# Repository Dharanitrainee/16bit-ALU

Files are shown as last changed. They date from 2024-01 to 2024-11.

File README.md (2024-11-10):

<h1>16-bit ALU with ESP32 Control Unit</h1>

<p>This project implements a 16-bit Arithmetic Logic Unit (ALU) using TTL (74 series) digital integrated circuits. The control unit is built using an ESP32 microcontroller, enhancing functionality with a user-friendly interface via an OLED display and a rotary encoder for selecting operations.</p>

<blockquote>
  <strong>Disclaimer</strong>: This is my first PCB design, and there may be flaws.This may be the worls worst ALU!. Any feedback or suggestions for improvement are welcome.
</blockquote>

<h2>Features</h2>

<ul>
  <li><strong>Arithmetic Operations</strong>: Addition, Subtraction, Increment, Decrement.</li>
  <li><strong>Logical Operations</strong>: AND, OR, XOR, NOT.</li>
  <li><strong>User Interface</strong>: An OLED display shows the current operation, and a rotary encoder allows for easy selection of operations.</li>
  <li><strong>Control Mechanism</strong>: ESP32 provides control signals and manages data flow within the ALU using shift registers.</li>
</ul>

<h2>Components Used</h2>

<ul>
  <li><strong>TTL ICs (74 series)</strong> for logic implementation</li>
  <li><strong>ESP32 microcontroller</strong> for control signals</li>
  <li><strong>OLED Display (SH1106)</strong> for displaying selected operation and result</li>
  <li><strong>Rotary Encoder (KY-040)</strong> for operation selection</li>
  <li><strong>Shift Registers (74HC595)</strong> for handling input/output</li>
</ul>

<h2>Project Structure</h2>

<ul>
  <li><code>main_code.ino</code>: The primary Arduino code for the ESP32, managing the control signals, encoder input, OLED output, and ALU operations.</li>
  <li><code>images/</code>: Contains bitmaps for icons representing each operation.</li>
  <li><code>README.md</code>: Project documentation.</li>
</ul>

<h2>How It Works</h2>

<ol>
  <li><strong>Control Unit</strong>: The ESP32 microcontroller generates control signals based on user input from the rotary encoder. The OLED screen displays the current operation, input values, and results.</li>
  <li><strong>ALU Operations</strong>: The ALU performs selected operations on 16-bit data, interfaced via shift registers.</li>
  <li><strong>Result Display</strong>: The result of the operation is shown on the OLED display.</li>
</ol>

<h2>Setup and Usage</h2>

<ol>
  <li>Connect the ESP32 to the OLED display and rotary encoder.</li>
  <li>Interface the shift registers with TTL ICs to implement the 16-bit ALU logic.</li>
  <li>Load the Arduino code onto the ESP32.</li>
  <li>Use the rotary encoder to select the desired operation and input values, then view the result on the OLED display.</li>
</ol>

<h2>Future Improvements</h2>

<ul>
  <li>Expand operations to include multiplication and division.</li>
  <li>Optimize the control signal generation for improved speed and accuracy.</li>
  <li>Add support for additional user inputs or controls to expand functionality.</li>
</ul>

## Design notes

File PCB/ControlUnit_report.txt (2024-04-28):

PCB statistics report
=====================
- Date: Sat 03 Feb 2024 10:58:33 PM IST
- Project: ControlUnit
- Board name: ControlUnit

Board
-----
- Width: 119.0000 mm
- Height: 119.3029 mm
- Area: 14175.4904 mm²

Pads
----
- Through hole: 217
- SMD: 88
- Connector: 0
- NPTH: 0

Vias
----
- Through vias: 27
- Blind/buried: 0
- Micro vias: 0

Components
----------

| | Front Side | Back Side | Total |
|---|---|---|---|
|THT: | 16 | 0 | 16 |
|SMD: | 31 | 0 | 31 |
|Unspecified:  | 4 | 0 | 4 |
|Total: | 51 | 0 | 51 |

Drill holes
-----------

| Count | Shape | X Size | Y Size | Plated | Via/Pad | Start Layer | Stop Layer |
|---|---|---|---|---|---|---|---|
| 80 | Round | 0.8000 mm | 0.8000 mm | PTH | Pad | F.Cu | B.Cu |
| 79 | Round | 0.5000 mm | 0.5000 mm | PTH | Pad | F.Cu | B.Cu |
| 38 | Round | 1.0200 mm | 1.0200 mm | PTH | Pad | F.Cu | B.Cu |
| 27 | Round | 0.3000 mm | 0.3000 mm | PTH | Via | F.Cu | B.Cu |
| 10 | Round | 1.0160 mm | 1.0160 mm | PTH | Pad | F.Cu | B.Cu |
| 4 | Round | 3.2000 mm | 3.2000 mm | PTH | Pad | F.Cu | B.Cu |
| 4 | Round | 1.0000 mm | 1.0000 mm | PTH | Pad | F.Cu | B.Cu |
| 2 | Round | 1.3000 mm | 1.3000 mm | PTH | Pad | F.Cu | B.Cu |

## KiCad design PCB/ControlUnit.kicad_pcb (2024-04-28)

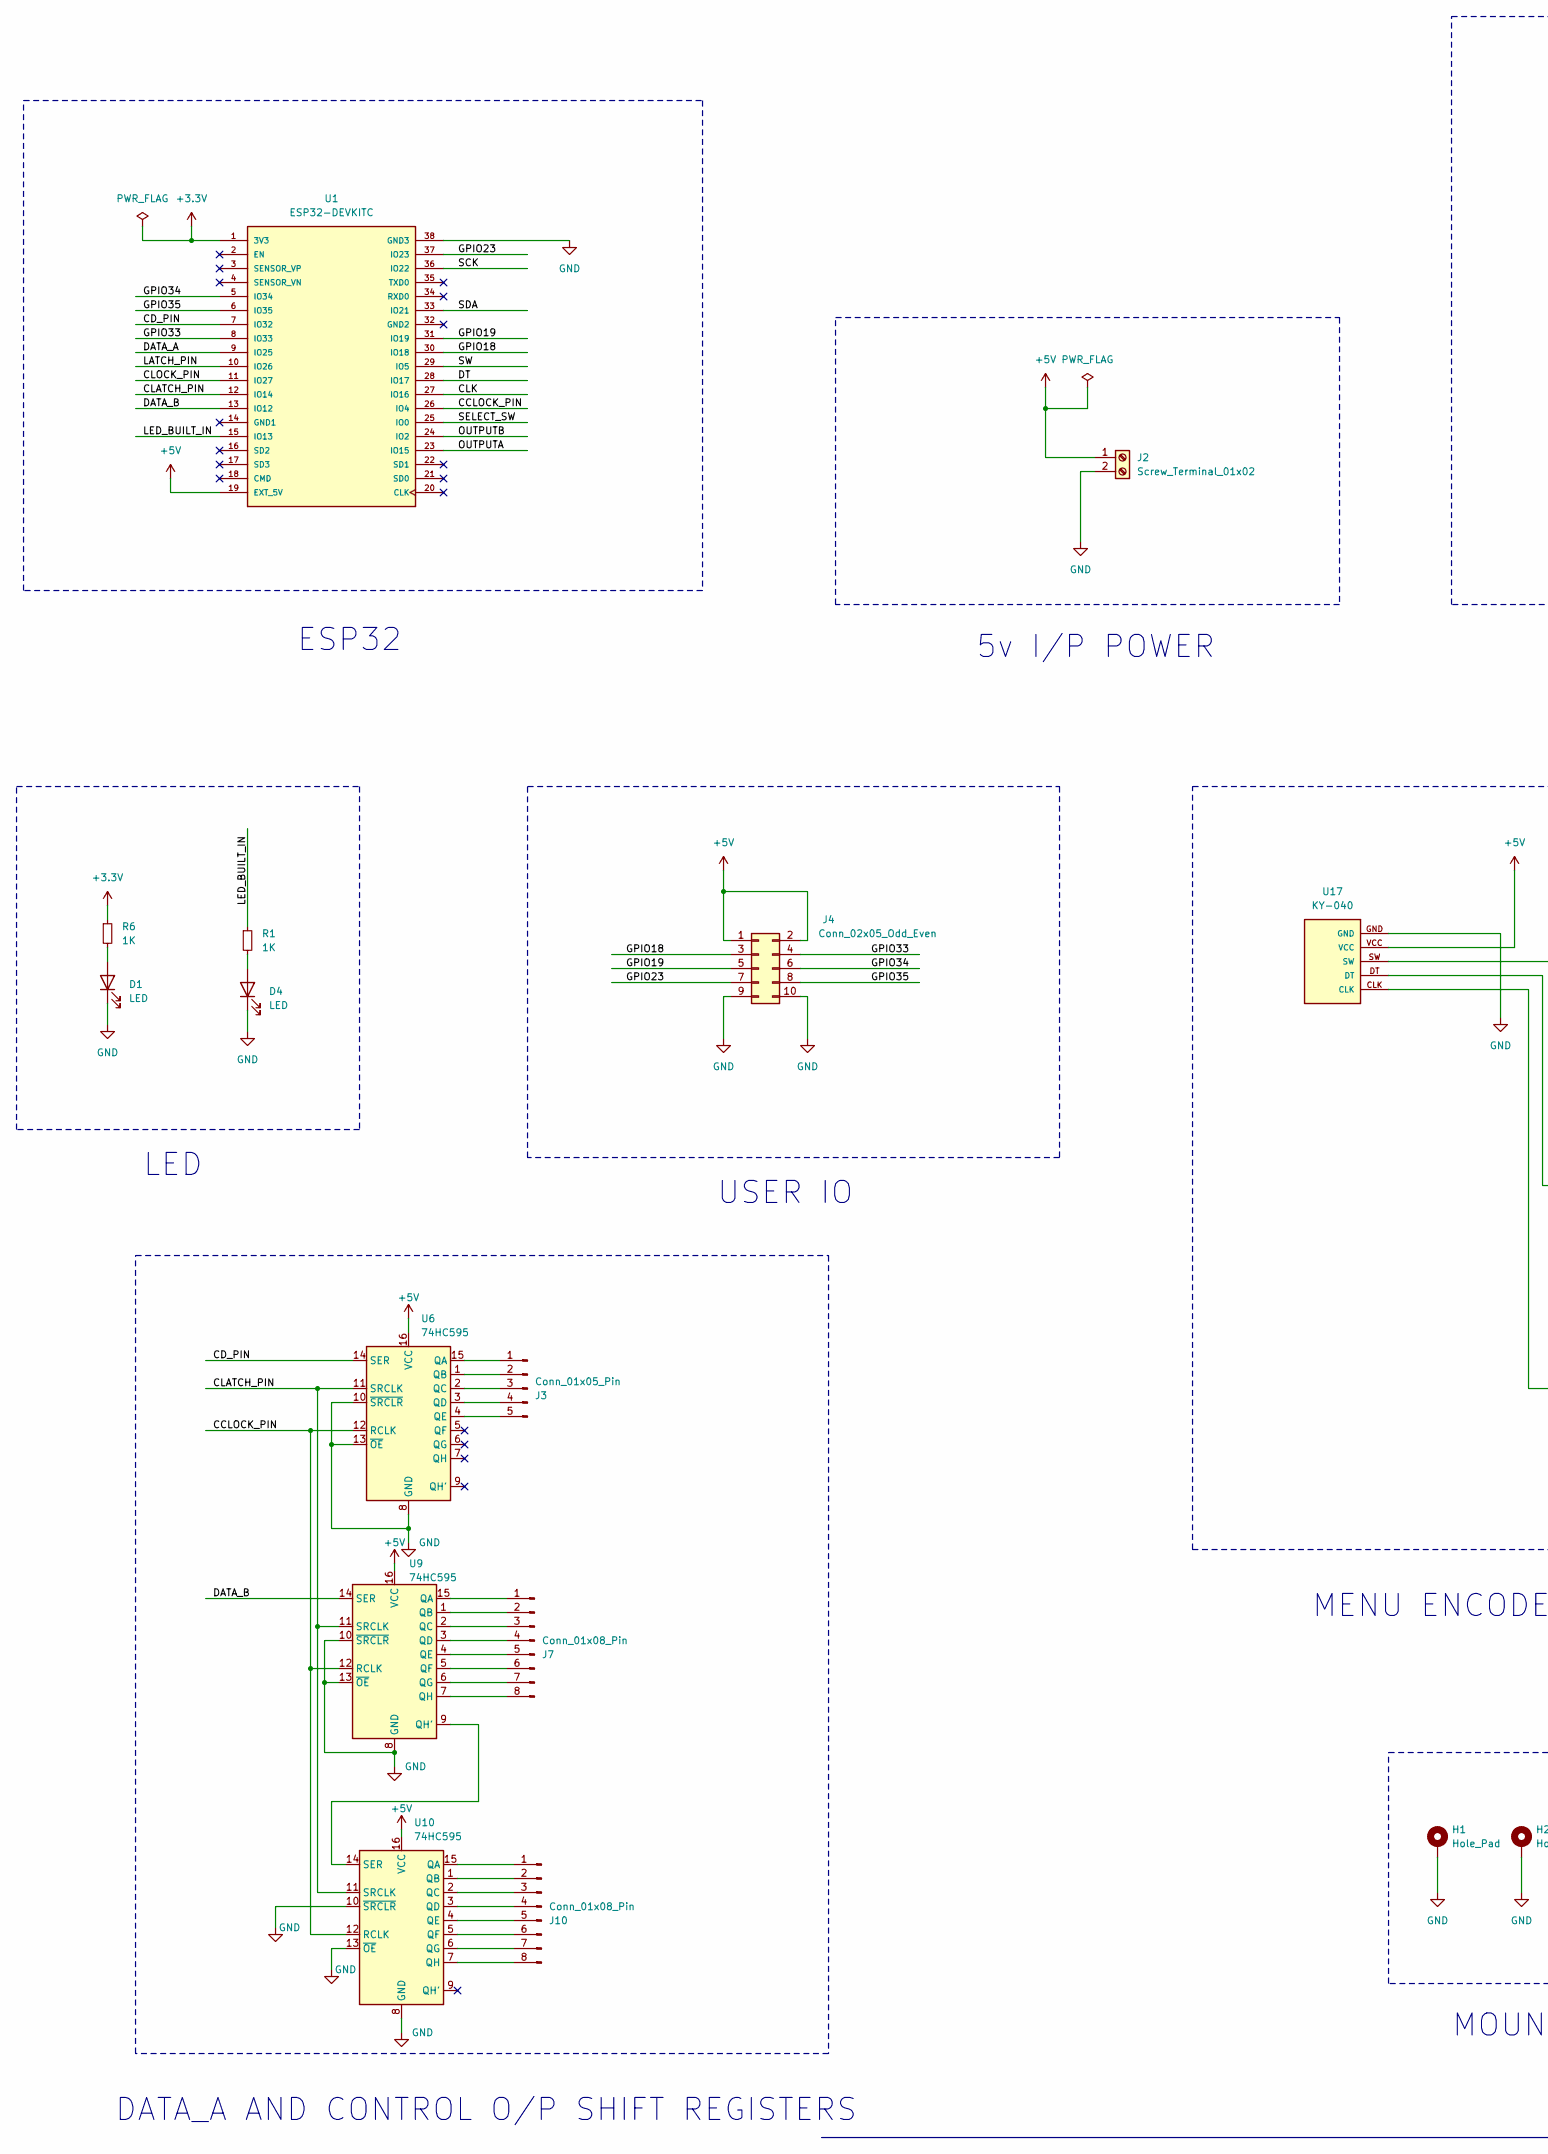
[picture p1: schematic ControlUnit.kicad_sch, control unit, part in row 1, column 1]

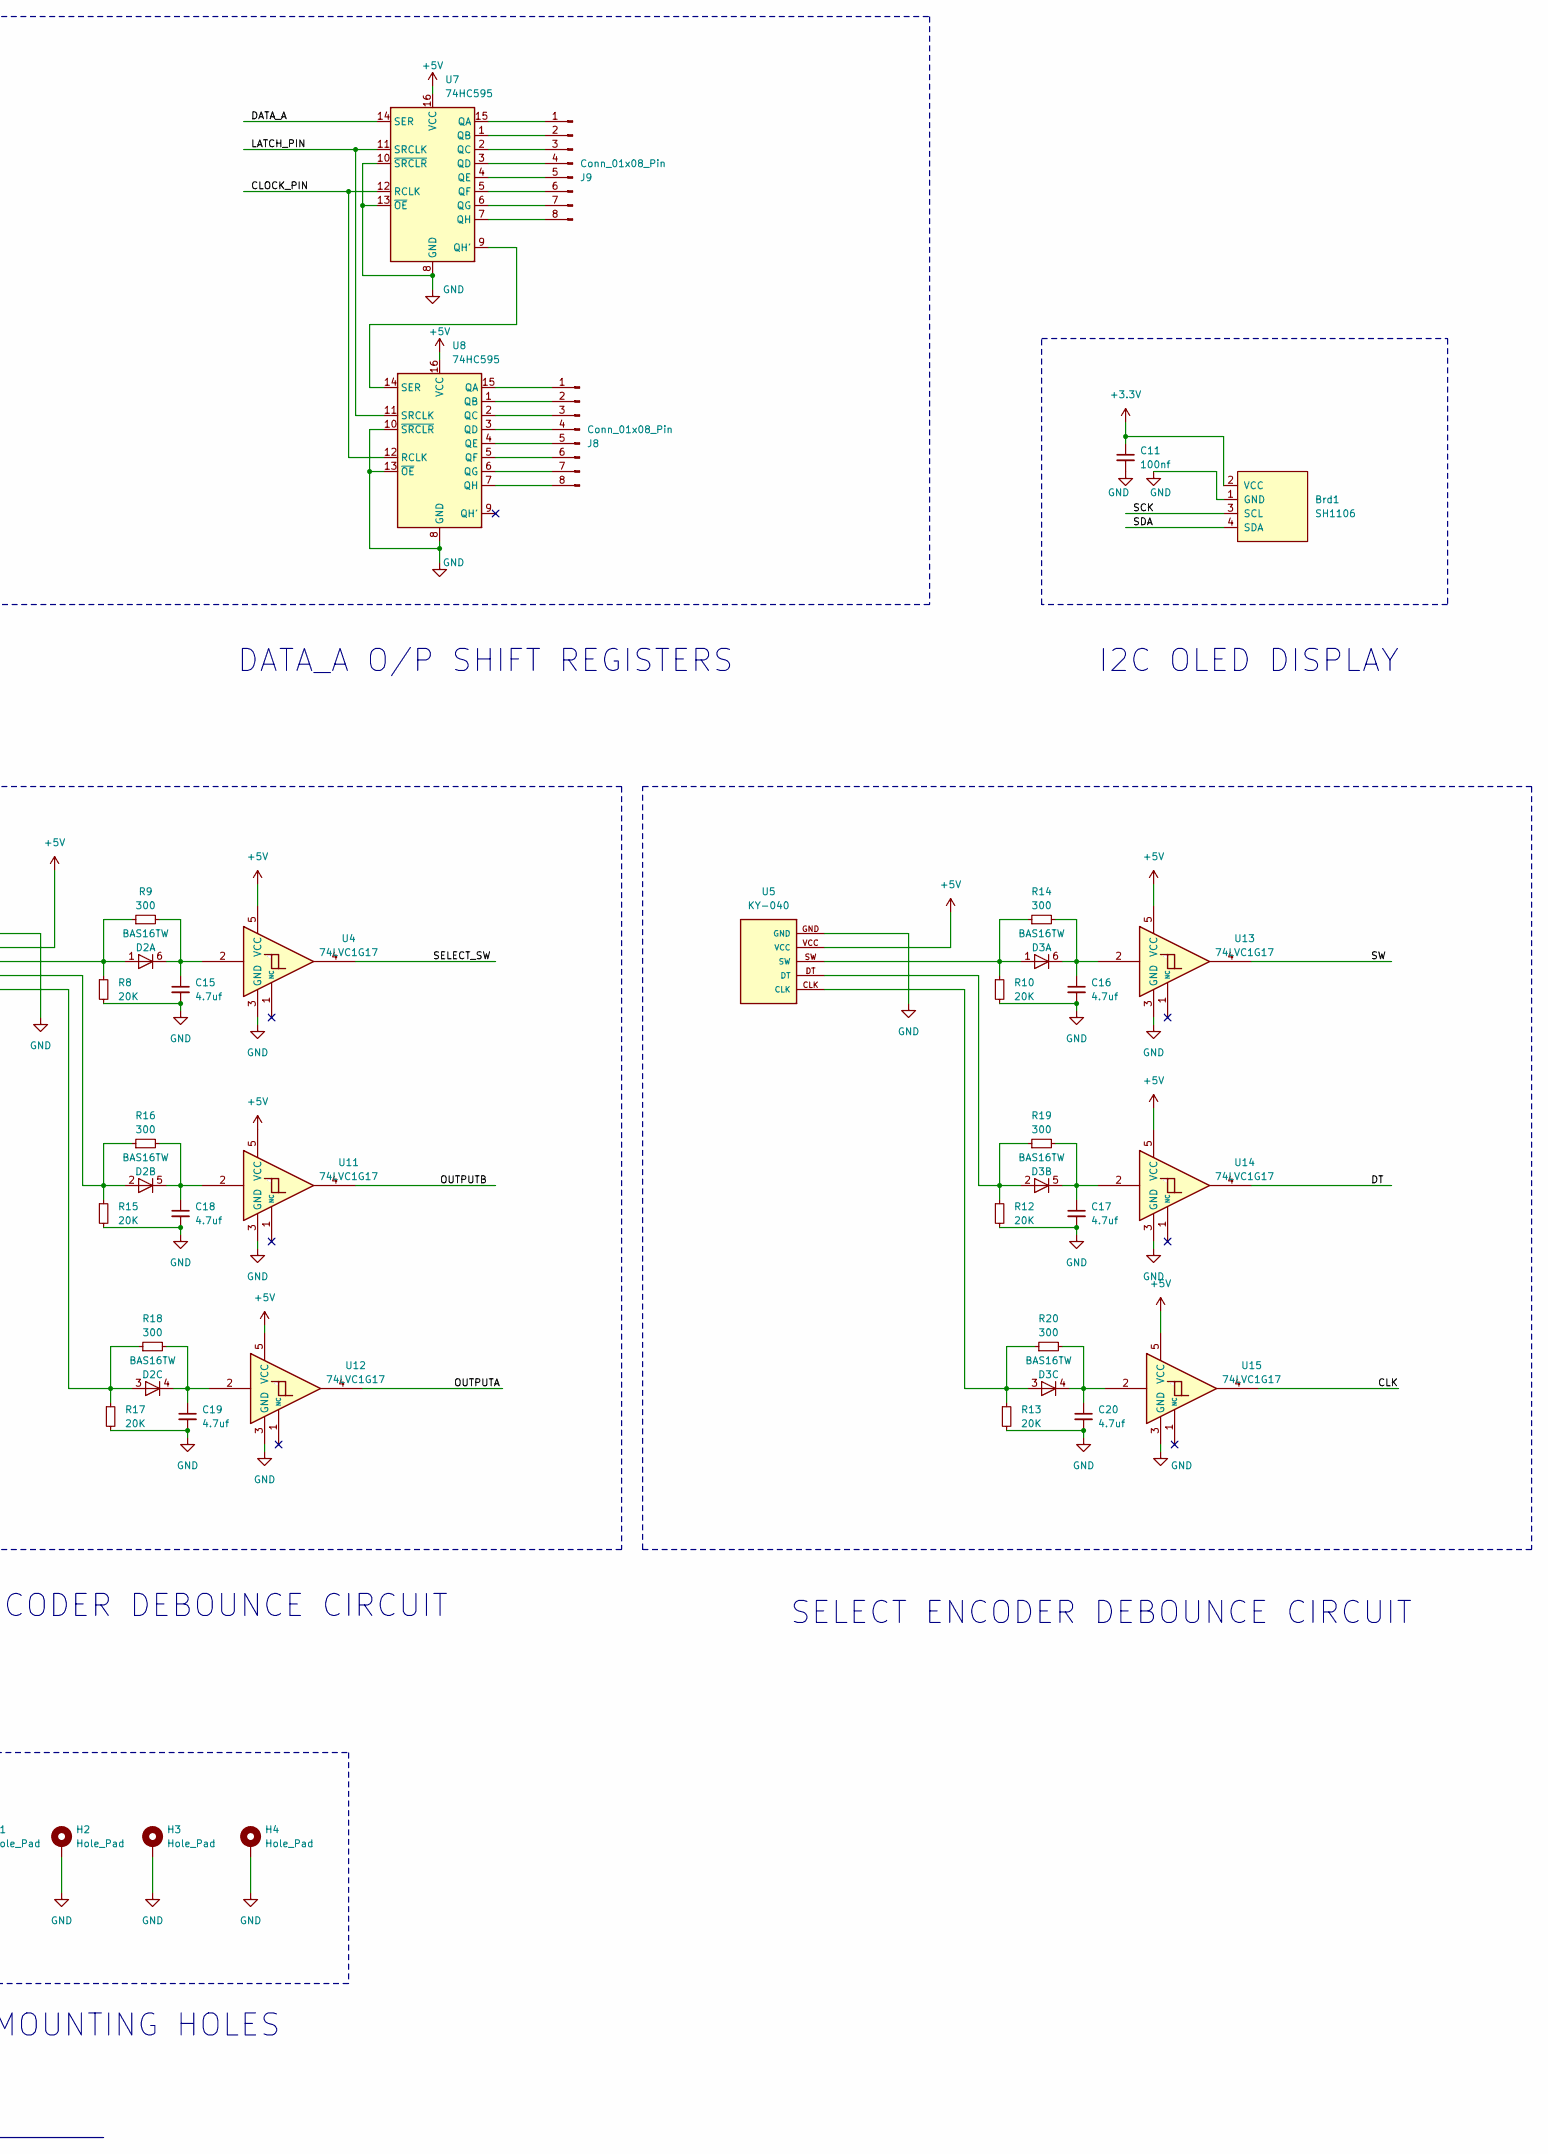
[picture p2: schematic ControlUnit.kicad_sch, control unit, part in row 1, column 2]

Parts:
Brd1: SH1106; 128x64OLED
C11: 100nf; C_0402_1005Metric_Pad0.74x0.62mm_HandSolder
C15, C16, C17, C18, C19, C20: 4.7uf; C_0805_2012Metric_Pad1.18x1.45mm_HandSolder
D1, D4: LED; LED_0603_1608Metric_Pad1.05x0.95mm_HandSolder
D2, D3: BAS16TW; SOT-363_SC-70-6
H1, H2, H3, H4: Hole_Pad; MountingHole_3.2mm_M3_Pad_Via
J2: Screw_Terminal_01x02; TerminalBlock_Phoenix_MKDS-1,5-2-5.08_1x02_P5.08mm_Horizont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
J3: Conn_01x05_Pin; PinHeader_1x05_P1.00mm_Vertical
J4: Conn_02x05_Odd_Even; PinHeader_2x05_P1.00mm_Vertical
J7, J8, J9, J10: Conn_01x08_Pin; PinHeader_1x08_P1.00mm_Vertical
R1, R6: 1K; R_0402_1005Metric_Pad0.72x0.64mm_HandSolder
R8, R10, R12, R13, R15, R17: 20K; R_0402_1005Metric_Pad0.72x0.64mm_HandSolder
R9, R14, R16, R18, R19, R20: 300; R_0402_1005Metric_Pad0.72x0.64mm_HandSolder
U1: ESP32-DEVKITC; MODULE_ESP32-DEVKITC; PARTREV N/A
U4, U11, U12, U13, U14, U15: 74LVC1G17; SOT23-5
U5, U17: KY-040; KY-040-PORT
U6, U7, U8, U9, U10: 74HC595; DIP-16_W10.16mm_LongPads

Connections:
+3.3V: Brd1.2 (VCC), C11.1, R6.1, U1.1 (3V3)
+5V: J2.1, J4.1, J4.2, U1.19 (EXT_5V), U4.5 (VCC), U5.VCC, U6.16 (VCC), U7.16 (VCC), U8.16 (VCC), U9.16 (VCC), U10.16 (VCC), U11.5 (VCC), U12.5 (VCC), U13.5 (VCC), U14.5 (VCC), U15.5 (VCC), U17.VCC
/CCLOCK_PIN: U1.26 (IO4), U6.12 (RCLK), U9.12 (RCLK), U10.12 (RCLK)
/CD_PIN: U1.7 (IO32), U6.14 (SER)
/CLATCH_PIN: U1.12 (IO14), U6.11 (SRCLK), U9.11 (SRCLK), U10.11 (SRCLK)
/CLK: U1.27 (IO16), U15.4
/CLOCK_PIN: U1.11 (IO27), U7.12 (RCLK), U8.12 (RCLK)
/DATA_A: U1.9 (IO25), U7.14 (SER)
/DATA_B: U1.13 (IO12), U9.14 (SER)
/DT: U1.28 (IO17), U14.4
/GPIO18: J4.3, U1.30 (IO18)
/GPIO19: J4.5, U1.31 (IO19)
/GPIO23: J4.7, U1.37 (IO23)
/GPIO33: J4.4, U1.8 (IO33)
/GPIO34: J4.6, U1.5 (IO34)
/GPIO35: J4.8, U1.6 (IO35)
/LATCH_PIN: U1.10 (IO26), U7.11 (SRCLK), U8.11 (SRCLK)
/LED_BUILT_IN: R1.1, U1.15 (IO13)
/OUTPUTA: U1.23 (IO15), U12.4
/OUTPUTB: U1.24 (IO2), U11.4
/SCK: Brd1.3 (SCL), U1.36 (IO22)
/SDA: Brd1.4 (SDA), U1.33 (IO21)
/SELECT_SW: U1.25 (IO0), U4.4
/SW: U1.29 (IO5), U13.4
GND: Brd1.1 (GND), C11.2, C15.2, C16.2, C17.2, C18.2, C19.2, C20.2, D1.1 (K), D4.1 (K), H1.1, H2.1, H3.1, H4.1, J2.2, J4.9, J4.10, R8.2, R10.2, R12.2, R13.2, R15.2, R17.2, U1.38 (GND3), U4.3 (GND), U5.GND, U6.8 (GND), U6.10 (~SRCLR), U6.13 (~OE), U7.8 (GND), U7.10 (~SRCLR), U7.13 (~OE), U8.8 (GND), U8.10 (~SRCLR), U8.13 (~OE), U9.8 (GND), U9.10 (~SRCLR), U9.13 (~OE), U10.8 (GND), U10.10 (~SRCLR), U10.13 (~OE), U11.3 (GND), U12.3 (GND), U13.3 (GND), U14.3 (GND), U15.3 (GND), U17.GND
unnamed: D1.2 (A), R6.2
unnamed: D2.1 (A), R8.1, R9.1, U17.SW
unnamed: C15.1, D2.6 (K), R9.2, U4.2
unnamed: D2.2 (A), R15.1, R16.1, U17.DT
unnamed: C18.1, D2.5 (K), R16.2, U11.2
unnamed: D2.3 (A), R17.1, R18.1, U17.CLK
unnamed: C19.1, D2.4 (K), R18.2, U12.2
unnamed: D3.1 (A), R10.1, R14.1, U5.SW
unnamed: C16.1, D3.6 (K), R14.2, U13.2
unnamed: D3.2 (A), R12.1, R19.1, U5.DT
unnamed: C17.1, D3.5 (K), R19.2, U14.2
unnamed: D3.3 (A), R13.1, R20.1, U5.CLK
unnamed: C20.1, D3.4 (K), R20.2, U15.2
unnamed: D4.2 (A), R1.2
unnamed: J3.1, U6.15 (QA)
unnamed: J3.2, U6.1 (QB)
unnamed: J3.3, U6.2 (QC)
unnamed: J3.4, U6.3 (QD)
unnamed: J3.5, U6.4 (QE)
unnamed: J7.1, U9.15 (QA)
unnamed: J7.2, U9.1 (QB)
unnamed: J7.3, U9.2 (QC)
unnamed: J7.4, U9.3 (QD)
unnamed: J7.5, U9.4 (QE)
unnamed: J7.6, U9.5 (QF)
unnamed: J7.7, U9.6 (QG)
unnamed: J7.8, U9.7 (QH)
unnamed: J8.1, U8.15 (QA)
unnamed: J8.2, U8.1 (QB)
unnamed: J8.3, U8.2 (QC)
unnamed: J8.4, U8.3 (QD)
unnamed: J8.5, U8.4 (QE)
unnamed: J8.6, U8.5 (QF)
unnamed: J8.7, U8.6 (QG)
unnamed: J8.8, U8.7 (QH)
unnamed: J9.1, U7.15 (QA)
unnamed: J9.2, U7.1 (QB)
unnamed: J9.3, U7.2 (QC)
unnamed: J9.4, U7.3 (QD)
unnamed: J9.5, U7.4 (QE)
unnamed: J9.6, U7.5 (QF)
unnamed: J9.7, U7.6 (QG)
unnamed: J9.8, U7.7 (QH)
unnamed: J10.1, U10.15 (QA)
unnamed: J10.2, U10.1 (QB)
unnamed: J10.3, U10.2 (QC)
unnamed: J10.4, U10.3 (QD)
unnamed: J10.5, U10.4 (QE)
unnamed: J10.6, U10.5 (QF)
unnamed: J10.7, U10.6 (QG)
unnamed: J10.8, U10.7 (QH)
unnamed: U7.9 (QH'), U8.14 (SER)
unnamed: U9.9 (QH'), U10.14 (SER)

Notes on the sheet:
5v I/P POWER
DATA_A O/P SHIFT REGISTERS
USER IO
SELECT ENCODER DEBOUNCE CIRCUIT
I2C OLED DISPLAY
DATA_A AND CONTROL O/P SHIFT REGISTERS
ESP32
LED
MENU ENCODER DEBOUNCE CIRCUIT
MOUNTING HOLES

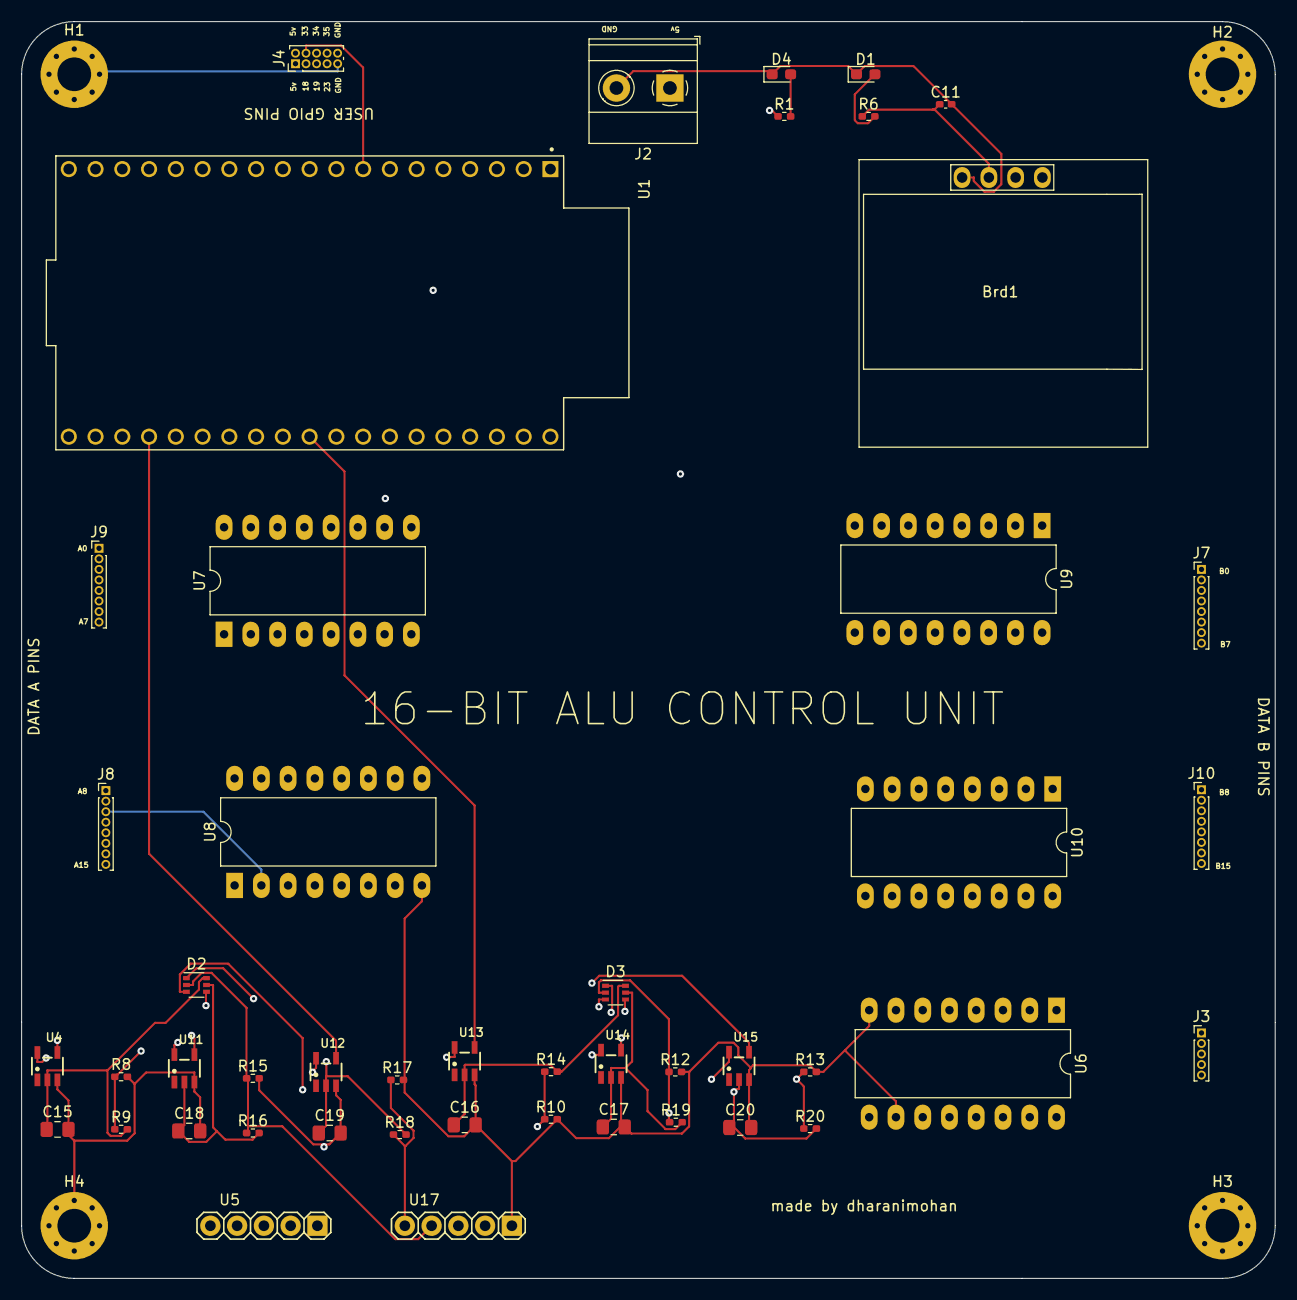
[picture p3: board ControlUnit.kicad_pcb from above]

Board: 4 copper layers, 119.0 x 119.3 mm, 51 parts (0 on the bottom side), 78 nets.

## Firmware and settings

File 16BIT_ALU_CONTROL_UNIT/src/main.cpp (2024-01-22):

#include <Wire.h>
#include <Adafruit_GFX.h>
#include <Adafruit_SH1106.h>

#define SDA 21
#define SCK 22
Adafruit_SH1106 display(SDA,SCK);

void setupOLED();
void displayMenuScreen();
void display_A_ValueSelectscreen();
void display_B_ValueSelectscreen();
void writeRegistersA(int DATA_A);
void writeRegistersAndControl(int DATA_B, int controlSignal);
void updateEncoder();
void select_ISR();
void encoder_ISR();
void value_select_ISR();
void check_rotary();

const unsigned char epd_bitmap__icon_AND [] PROGMEM = {
	0x00, 0x00, 0x07, 0xc0, 0x18, 0x30, 0x20, 0x08, 0x40, 0x04, 0x41, 0x04, 0x82, 0x82, 0x84, 0x42, 
	0x88, 0x22, 0x8f, 0xe2, 0x88, 0x22, 0x48, 0x24, 0x40, 0x04, 0x20, 0x08, 0x18, 0x30, 0x07, 0xc0
};

const unsigned char epd_bitmap__icon_addition [] PROGMEM = {
	0x07, 0xe0, 0x18, 0x18, 0x20, 0x04, 0x50, 0x02, 0x41, 0x82, 0x81, 0x81, 0x81, 0x81, 0x8f, 0xf1, 
	0x8f, 0xf1, 0x81, 0x81, 0x81, 0x81, 0x41, 0x82, 0x40, 0x02, 0x20, 0x04, 0x18, 0x18, 0x07, 0xe0
};

const unsigned char epd_bitmap__item_sel_outline [] PROGMEM = {
  0x1f, 0xff, 0xff, 0xff, 0xff, 0xff, 0xff, 0xff, 0xff, 0xff, 0xff, 0xff, 0xff, 0xff, 0xff, 0xc0, 
	0x20, 0x00, 0x00, 0x00, 0x00, 0x00, 0x00, 0x00, 0x00, 0x00, 0x00, 0x00, 0x00, 0x00, 0x00, 0x20, 
	0x40, 0x00, 0x00, 0x00, 0x00, 0x00, 0x00, 0x00, 0x00, 0x00, 0x00, 0x00, 0x00, 0x00, 0x00, 0x10, 
	0x40, 0x00, 0x00, 0x00, 0x00, 0x00, 0x00, 0x00, 0x00, 0x00, 0x00, 0x00, 0x00, 0x00, 0x00, 0x10, 
	0x40, 0x00, 0x00, 0x00, 0x00, 0x00, 0x00, 0x00, 0x00, 0x00, 0x00, 0x00, 0x00, 0x00, 0x00, 0x10, 
	0x40, 0x00, 0x00, 0x00, 0x00, 0x00, 0x00, 0x00, 0x00, 0x00, 0x00, 0x00, 0x00, 0x00, 0x00, 0x10, 
	0x40, 0x00, 0x00, 0x00, 0x00, 0x00, 0x00, 0x00, 0x00, 0x00, 0x00, 0x00, 0x00, 0x00, 0x00, 0x10, 
	0x40, 0x00, 0x00, 0x00, 0x00, 0x00, 0x00, 0x00, 0x00, 0x00, 0x00, 0x00, 0x00, 0x00, 0x00, 0x10, 
	0x40, 0x00, 0x00, 0x00, 0x00, 0x00, 0x00, 0x00, 0x00, 0x00, 0x00, 0x00, 0x00, 0x00, 0x00, 0x10, 
	0x40, 0x00, 0x00, 0x00, 0x00, 0x00, 0x00, 0x00, 0x00, 0x00, 0x00, 0x00, 0x00, 0x00, 0x00, 0x10, 
	0x40, 0x00, 0x00, 0x00, 0x00, 0x00, 0x00, 0x00, 0x00, 0x00, 0x00, 0x00, 0x00, 0x00, 0x00, 0x10, 
	0x40, 0x00, 0x00, 0x00, 0x00, 0x00, 0x00, 0x00, 0x00, 0x00, 0x00, 0x00, 0x00, 0x00, 0x00, 0x10, 
	0x40, 0x00, 0x00, 0x00, 0x00, 0x00, 0x00, 0x00, 0x00, 0x00, 0x00, 0x00, 0x00, 0x00, 0x00, 0x10, 
	0x40, 0x00, 0x00, 0x00, 0x00, 0x00, 0x00, 0x00, 0x00, 0x00, 0x00, 0x00, 0x00, 0x00, 0x00, 0x10, 
	0x40, 0x00, 0x00, 0x00, 0x00, 0x00, 0x00, 0x00, 0x00, 0x00, 0x00, 0x00, 0x00, 0x00, 0x00, 0x10, 
	0x40, 0x00, 0x00, 0x00, 0x00, 0x00, 0x00, 0x00, 0x00, 0x00, 0x00, 0x00, 0x00, 0x00, 0x00, 0x10, 
	0x40, 0x00, 0x00, 0x00, 0x00, 0x00, 0x00, 0x00, 0x00, 0x00, 0x00, 0x00, 0x00, 0x00, 0x00, 0x10, 
	0x40, 0x00, 0x00, 0x00, 0x00, 0x00, 0x00, 0x00, 0x00, 0x00, 0x00, 0x00, 0x00, 0x00, 0x00, 0x10, 
	0x40, 0x00, 0x00, 0x00, 0x00, 0x00, 0x00, 0x00, 0x00, 0x00, 0x00, 0x00, 0x00, 0x00, 0x00, 0x30, 
	0x3f, 0xff, 0xff, 0xff, 0xff, 0xff, 0xff, 0xff, 0xff, 0xff, 0xff, 0xff, 0xff, 0xff, 0xff, 0xe0, 
	0x1f, 0xff, 0xff, 0xff, 0xff, 0xff, 0xff, 0xff, 0xff, 0xff, 0xff, 0xff, 0xff, 0xff, 0xff, 0xc0
};

const unsigned char epd_bitmap__icon_subtraction [] PROGMEM = {
0x0f, 0xe0, 0x30, 0x18, 0x40, 0x04, 0x40, 0x06, 0x80, 0x02, 0x80, 0x02, 0x9f, 0xfa, 0x9f, 0xfa, 
	0x9f, 0xfa, 0x80, 0x02, 0x80, 0x02, 0x40, 0x04, 0x40, 0x04, 0x30, 0x18, 0x0f, 0xe0
};

const unsigned char epd_bitmap__scrollbar_background [] PROGMEM = {
	0x00, 0x02, 0x00, 0x02, 0x00, 0x02, 0x00, 0x02, 0x00, 0x02, 0x00, 0x02, 0x00, 0x02, 0x00, 0x02, 
	0x00, 0x02, 0x00, 0x02, 0x00, 0x02, 0x00, 0x02, 0x00, 0x02, 0x00, 0x02, 0x00, 0x02, 0x00, 0x02, 
	0x00, 0x02, 0x00, 0x02, 0x00, 0x02, 0x00, 0x02, 0x00, 0x02, 0x00, 0x02, 0x00, 0x02, 0x00, 0x02, 
	0x00, 0x02, 0x00, 0x02, 0x00, 0x02, 0x00, 0x02, 0x00, 0x02, 0x00, 0x02, 0x00, 0x02, 0x00, 0x00
};

const unsigned char epd_bitmap_icon_a_invert_ [] PROGMEM = {
	0x00, 0x00, 0x00, 0x00, 0x03, 0xc0, 0x0c, 0x30, 0x10, 0x08, 0x17, 0xe8, 0x20, 0x04, 0x21, 0x04, 
	0x22, 0x84, 0x24, 0x44, 0x17, 0xc8, 0x14, 0x48, 0x0c, 0x30, 0x03, 0xc0, 0x00, 0x00, 0x00, 0x00
};

const unsigned char epd_bitmap_icon_a_inc [] PROGMEM = {
	0x00, 0x00, 0x00, 0x00, 0x03, 0xc0, 0x0c, 0x30, 0x10, 0x48, 0x10, 0xe8, 0x20, 0x44, 0x21, 0x04, 
	0x22, 0x84, 0x24, 0x44, 0x17, 0xc8, 0x14, 0x48, 0x0c, 0x30, 0x03, 0xc0, 0x00, 0x00, 0x00, 0x00
};

const unsigned char epd_bitmap_icon_a_dec [] PROGMEM = {
	0x00, 0x00, 0x00, 0x00, 0x03, 0xc0, 0x0c, 0x30, 0x10, 0x08, 0x10, 0xe8, 0x20, 0x04, 0x21, 0x04, 
	0x22, 0x84, 0x24, 0x44, 0x17, 0xc8, 0x14, 0x48, 0x0c, 0x30, 0x03, 0xc0, 0x00, 0x00, 0x00, 0x00
};

const unsigned char epd_bitmap_icon_or [] PROGMEM = {
	0x00, 0x00, 0x00, 0x00, 0x03, 0xc0, 0x0c, 0x30, 0x10, 0x08, 0x13, 0x88, 0x24, 0x44, 0x24, 0x44, 
	0x24, 0x44, 0x24, 0x44, 0x13, 0x88, 0x10, 0x08, 0x0c, 0x30, 0x03, 0xc0, 0x00, 0x00, 0x00, 0x00
};

const unsigned char epd_bitmap_icon_xor [] PROGMEM = {
	0x00, 0x00, 0x00, 0x00, 0x03, 0xc0, 0x0c, 0x30, 0x10, 0x08, 0x14, 0x28, 0x22, 0x44, 0x21, 0x84, 
	0x21, 0x84, 0x22, 0x44, 0x14, 0x28, 0x10, 0x08, 0x0c, 0x30, 0x03, 0xc0, 0x00, 0x00, 0x00, 0x00
};

const int epd_bitmap_allArray_LEN = 8;
const unsigned char* epd_bitmap_allArray[8] = {
	epd_bitmap__icon_AND,
	epd_bitmap__icon_addition,
	epd_bitmap__icon_subtraction,
  epd_bitmap_icon_a_invert_,
	epd_bitmap_icon_a_inc,
	epd_bitmap_icon_a_dec,
	epd_bitmap_icon_or,
	epd_bitmap_icon_xor
};

const int NUM_ITEMS = 8;

char menu_items[NUM_ITEMS] [20] = {
  {"AND"},
	{"Addition"},
	{"Subtraction"},
  {"Invert A"},
  {"Increment A"},
  {"Decrement A"},
  {"OR"},
  {"XOR"}
};

const int AND_SIGNAL = 7;
const int ADDITION_SIGNAL = 0;
const int SUBTRACTION_SIGNAL = 3;
const int INVERT_A_SIGNAL = 31;
const int INCREMENT_A_SIGNAL = 2;
const int DECREMENT_A_SIGNAL = 3;
const int OR_SIGNAL = 12;
const int XOR_SIGNAL = 23;

const unsigned int control_signals[NUM_ITEMS] = {
  AND_SIGNAL,
  ADDITION_SIGNAL,
  SUBTRACTION_SIGNAL,
  INVERT_A_SIGNAL,
  INCREMENT_A_SIGNAL,
  DECREMENT_A_SIGNAL,
  OR_SIGNAL,
  XOR_SIGNAL
};

//Menu encoder pins
#define outputA 15 
#define outputB 2
#define select_sw 0

//Value select encoder pins
#define clk 16
#define dt 17
#define sw 5

//Data shift register pins
#define DATA_PIN  25 
#define LATCH_PIN 26  
#define CLOCK_PIN 27 
#define DATAB_PIN 12

//controlbits shift register pins
#define CD_PIN 32
#define CLATCH_PIN 14
#define CCLOCK_PIN 4


int item_selected = 0;
int item_sel_previous;
int item_sel_next;

volatile int current_screen = 0;
int button_select_clicked = 0;
int value_select_clicked = 0;

volatile int encoderValue;
volatile long data_a = 0,data_b = 0;

int PreviousCLK;
int PreviousDATA;


long TimeofLastDebounce = 0;
int debounceDelay = 10;


void writeRegistersA(int DATA_A)
{
  digitalWrite(LATCH_PIN,LOW);
  shiftOut(DATA_PIN,CLOCK_PIN,MSBFIRST,DATA_A);
  digitalWrite(LATCH_PIN, HIGH);
  digitalWrite(LATCH_PIN, LOW);
}

void writeRegistersAndControl(int DATA_B, int controlSignal) {
  digitalWrite(CLATCH_PIN, LOW);
  shiftOut(DATAB_PIN, CCLOCK_PIN, LSBFIRST, DATA_B);
  shiftOut(CD_PIN, CCLOCK_PIN, MSBFIRST, controlSignal);
  digitalWrite(CLATCH_PIN, HIGH);
  digitalWrite(CLATCH_PIN, LOW);
}

void reset()
    {writeRegistersAndControl(0,0);
  writeRegistersA(0);
}

void check_rotary(){
  if((PreviousCLK == 0) && (PreviousDATA == 1))
  {
    if((digitalRead(clk) == 1) && (digitalRead(dt) == 0)){
      encoderValue++;
    }
    if((digitalRead(clk) == 1) && (digitalRead(dt) == 1)){
      encoderValue--;
    }
  }
  if((PreviousCLK == 1) && (PreviousDATA == 0))
  {
    if((digitalRead(clk) == 0) && (digitalRead(dt) == 1)){
      encoderValue++;
    }
    if((digitalRead(clk) == 0) && (digitalRead(dt) == 0)){
      encoderValue--;
    }
  }
  if((PreviousCLK == 1) && (PreviousDATA == 1))
  {
    if((digitalRead(clk) == 0) && (digitalRead(dt) == 1)){
      encoderValue++;
    }
    if((digitalRead(clk) == 0) && (digitalRead(dt) == 0)){
      encoderValue--;
    }
  }
  if((PreviousCLK == 0) && (PreviousDATA == 0))
  {
    if((digitalRead(clk) == 1) && (digitalRead(dt) == 0)){
      encoderValue++;
    }
    if((digitalRead(clk) == 1) && (digitalRead(dt) == 1)){
      encoderValue--;
    }
  }
  encoderValue = constrain(encoderValue, 0, 65535);
}

void updateEncoder()
{
  static unsigned long lastDebounceTime = 0;
  static int lastEncodedA = 0;
  static int lastEncodedB = 0;
  int MSB = digitalRead(outputA);
  int LSB = digitalRead(outputB);
  int encoded = (MSB << 1) | LSB;
   int sum = (lastEncodedA << 3) | (lastEncodedB << 2) | (encoded << 1) | (encoded);
   if(millis() -lastDebounceTime > debounceDelay){
    if((sum == 0b1101 || sum == 0b0100 || sum == 0b0010 || sum == 0b1011) && current_screen == 0)
    {
      item_selected = item_selected-1;
      if(item_selected < 0){
      item_selected = NUM_ITEMS - 1;
    }
     }
    else if ((sum == 0b1110 || sum == 0b0111 || sum == 0b0001 || sum == 0b1000) && current_screen == 0) {
      item_selected = item_selected + 1;
      if(item_selected >= NUM_ITEMS){
        item_selected = 0;
      }
    }
  lastEncodedA = MSB;
  lastEncodedB = LSB;
  lastDebounceTime = millis();
   }
  }


void select_ISR()
{
   if((digitalRead(select_sw)  == LOW) && (button_select_clicked == 0)){
      button_select_clicked = 1;
      if(current_screen == 0){current_screen = 1;}
      else if(current_screen == 1){current_screen = 0;}
      else{current_screen = 0;}
    }
    if(digitalRead(select_sw) == HIGH && (button_select_clicked == 1)){
      button_select_clicked = 0;
    }
}

void encoder_ISR(){
  if((millis() - TimeofLastDebounce) > debounceDelay){
    check_rotary();
  }
  PreviousCLK = digitalRead(clk);
  PreviousDATA = digitalRead(dt);
  TimeofLastDebounce = millis();
}



void value_select_ISR() {
  int swState = digitalRead(sw);

  if (swState == LOW && value_select_clicked == 0) {
    value_select_clicked = 1;

    if (current_screen == 1) {
      current_screen = 2;
      data_a = encoderValue;
      encoderValue = 0;
    } else if (current_screen == 2) {
      current_screen = 3;
      if(control_signals[item_selected+1] == INCREMENT_A_SIGNAL){
      data_b = 0;
      }
      else if(control_signals[item_selected+1] == DECREMENT_A_SIGNAL){
      data_b = 1;
      }
      else{
      data_b = encoderValue;}
      writeRegistersA(data_a);
      writeRegistersAndControl(data_b,control_signals[item_selected+1]);
    } else {
      current_screen = 0;
      encoderValue = 0;
    }
  }

  if (swState == HIGH && value_select_clicked == 1) {
    value_select_clicked = 0;
  }
}


void displayWelcomeScreen()
{
  display.clearDisplay();
  display.setCursor(45, 30);
  display.setTextSize(1);
  display.setTextColor(WHITE);
  display.print("WELCOME");
  display.display();
  delay(500);
  display.clearDisplay();
}

void setupOLED()
{
  display.begin(SH1106_SWITCHCAPVCC, 0x3c);
  delay(1000);
  display.clearDisplay();
  displayWelcomeScreen();
} 

void displayMenuScreen()
{
  if(current_screen == 0){
  item_sel_previous = item_selected - 1;
  if (item_sel_previous < 0) {item_sel_previous = NUM_ITEMS - 1;}
  item_sel_next = item_selected + 1;  
  if (item_sel_next >= NUM_ITEMS) {item_sel_next = 0;}
  display.setTextSize(1);
  display.setTextColor(WHITE);

  display.setCursor(25,50);
  display.print(menu_items[item_sel_previous]);
  display.drawBitmap(4,46,epd_bitmap_allArray[item_sel_previous],16,16,1);

  display.setCursor(25,10);
  display.print(menu_items[item_selected]);   
  display.drawBitmap(4,06,epd_bitmap_allArray[item_selected],16,16,1);

  display.setCursor(25,30);
  display.print(menu_items[item_sel_next]);
  display.drawBitmap(4,26,epd_bitmap_allArray[item_sel_next],15,15,1);

  display.drawBitmap(0,22,epd_bitmap__item_sel_outline,128,21,1);
  display.drawBitmap(120,0,epd_bitmap__scrollbar_background,8,64,1);
  display.display();
  display.clearDisplay();
  }
}

void display_A_ValueSelectscreen()
{
  display.clearDisplay();
  display.setTextSize(1);
  display.setTextColor(WHITE);
  display.drawBitmap(100,8,epd_bitmap_allArray[item_selected+1],16,16,1);
  display.setCursor(30,20);
  display.print("Select A");
  display.setCursor(30,40);
  display.print(encoderValue);
  display.display();
}

void display_B_ValueSelectscreen()
{
  display.clearDisplay();
  display.setTextSize(1);
  display.setTextColor(WHITE);
  display.drawBitmap(100,8,epd_bitmap_allArray[item_selected+1],16,16,1);
  display.setCursor(30,20);
  display.print("Select B");
  display.setCursor(30,40);
  display.print(encoderValue);
  display.display();
}

void displayResultScreen()
{
  display.clearDisplay();
  display.setTextSize(1);
  display.setTextColor(WHITE);
  display.drawBitmap(100,8,epd_bitmap_allArray[item_selected+1],16,16,1);
  display.setCursor(30,30);
  display.print("Result");
  display.display();
}

void setup() {
  Serial.begin(115200);
  pinMode(outputA, INPUT_PULLUP);
  pinMode(outputB, INPUT_PULLUP);
  pinMode(select_sw, INPUT_PULLUP);
  pinMode(DATA_PIN, OUTPUT);
  pinMode(CLOCK_PIN, OUTPUT);
  pinMode(LATCH_PIN, OUTPUT);
  pinMode(clk, INPUT_PULLUP);
  pinMode(dt, INPUT_PULLUP);
  pinMode(sw, INPUT_PULLUP);
  pinMode(CD_PIN,OUTPUT);
  pinMode(CLATCH_PIN,OUTPUT);
  pinMode(CCLOCK_PIN,OUTPUT);
  pinMode(DATAB_PIN,OUTPUT);

  attachInterrupt(digitalPinToInterrupt(outputA), updateEncoder, CHANGE);
  attachInterrupt(digitalPinToInterrupt(outputB), updateEncoder, CHANGE);
  attachInterrupt(digitalPinToInterrupt(select_sw), select_ISR, CHANGE);
  attachInterrupt(digitalPinToInterrupt(clk), encoder_ISR, CHANGE);
  attachInterrupt(digitalPinToInterrupt(dt), encoder_ISR, CHANGE);
  attachInterrupt(digitalPinToInterrupt(sw), value_select_ISR, CHANGE);

  setupOLED();

  PreviousCLK = digitalRead(clk);
  PreviousDATA = digitalRead(dt);
  }
 
void loop() {
switch(current_screen){
  case 0:
  displayMenuScreen();
  reset();
  break;
  case 1:
  display_A_ValueSelectscreen();
  break;
  case 2:
  display_B_ValueSelectscreen();
  break;
  case 3:
  displayResultScreen();
  break;
}
}
